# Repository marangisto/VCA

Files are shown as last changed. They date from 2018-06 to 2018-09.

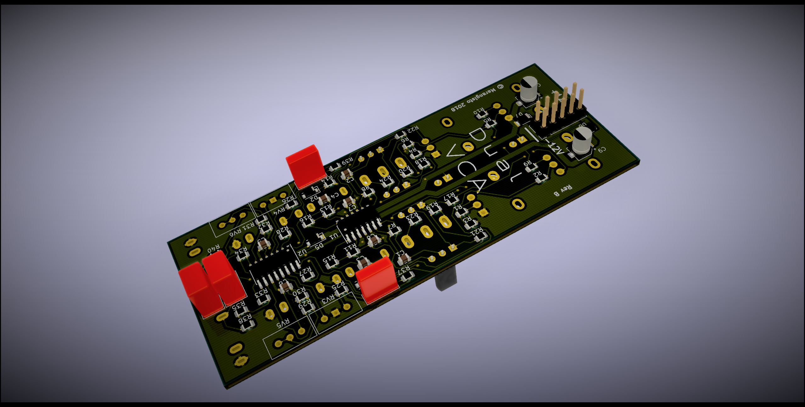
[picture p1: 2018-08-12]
board-RevB.png

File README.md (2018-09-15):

# VCA
DIY Modular VCA

Inspired by RJWSoft's Dual Log/Linear VCA but incorporating ideas from application notes
and use of the diode bias inputs in the OTA together with supply adjustements
to ensure both exponential and linear modes can drive levels all the way to zero.

To calibrate:

1) Set offset potentiometer so that its output viper is at 0V (measure on board).

2) Adjust the 100k trimmer (bottom-most) as close to 0mV as possible at output jack.
note that during this phase you may need to mix in adjustments of the 2k trimmer
to make this feasible.

3) Feed a 100Hz 10Vpp square signal into CV and adjust 2k trimmer (top-most) to minimize
feed-throgh on an oscilloscope.

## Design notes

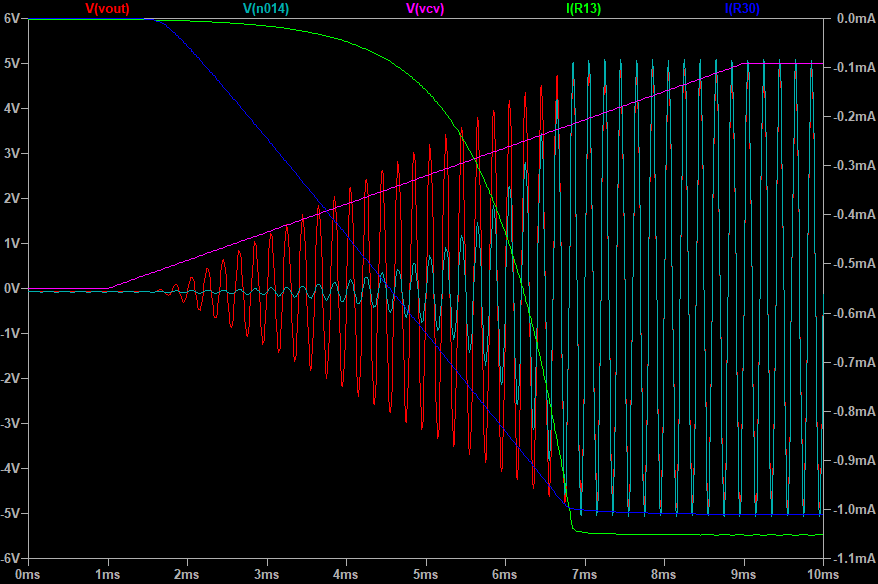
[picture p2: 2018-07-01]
response.png

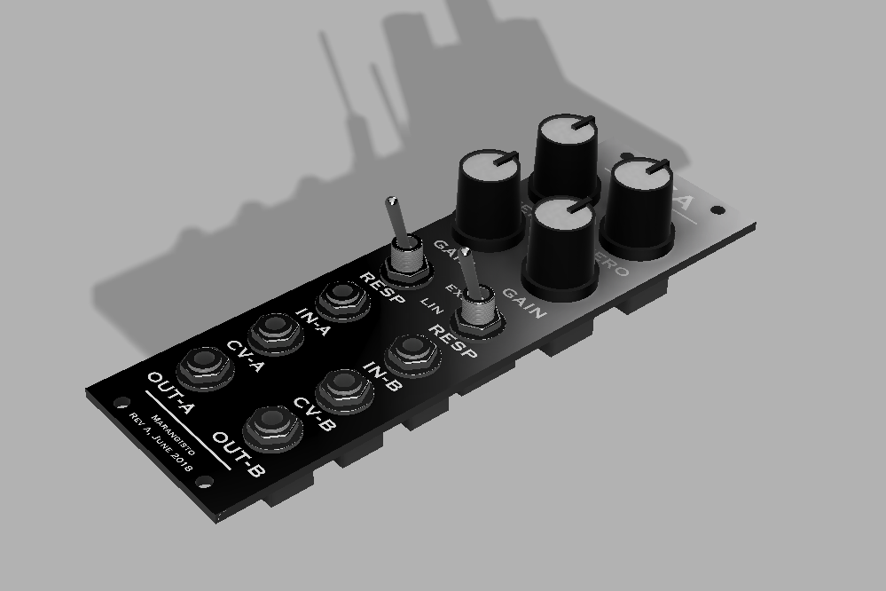
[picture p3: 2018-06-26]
vca-render.png

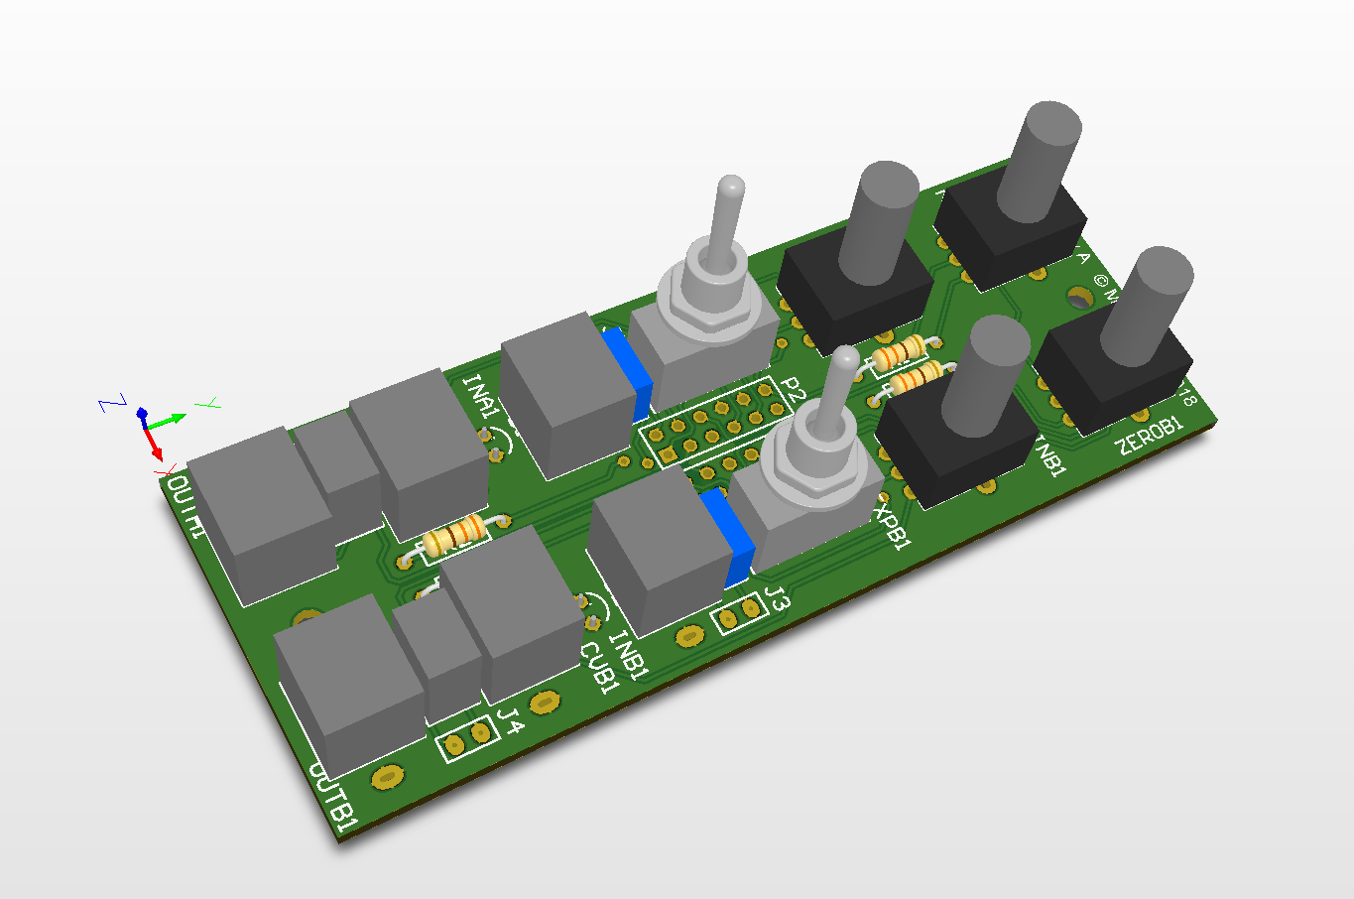
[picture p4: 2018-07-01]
ui.png

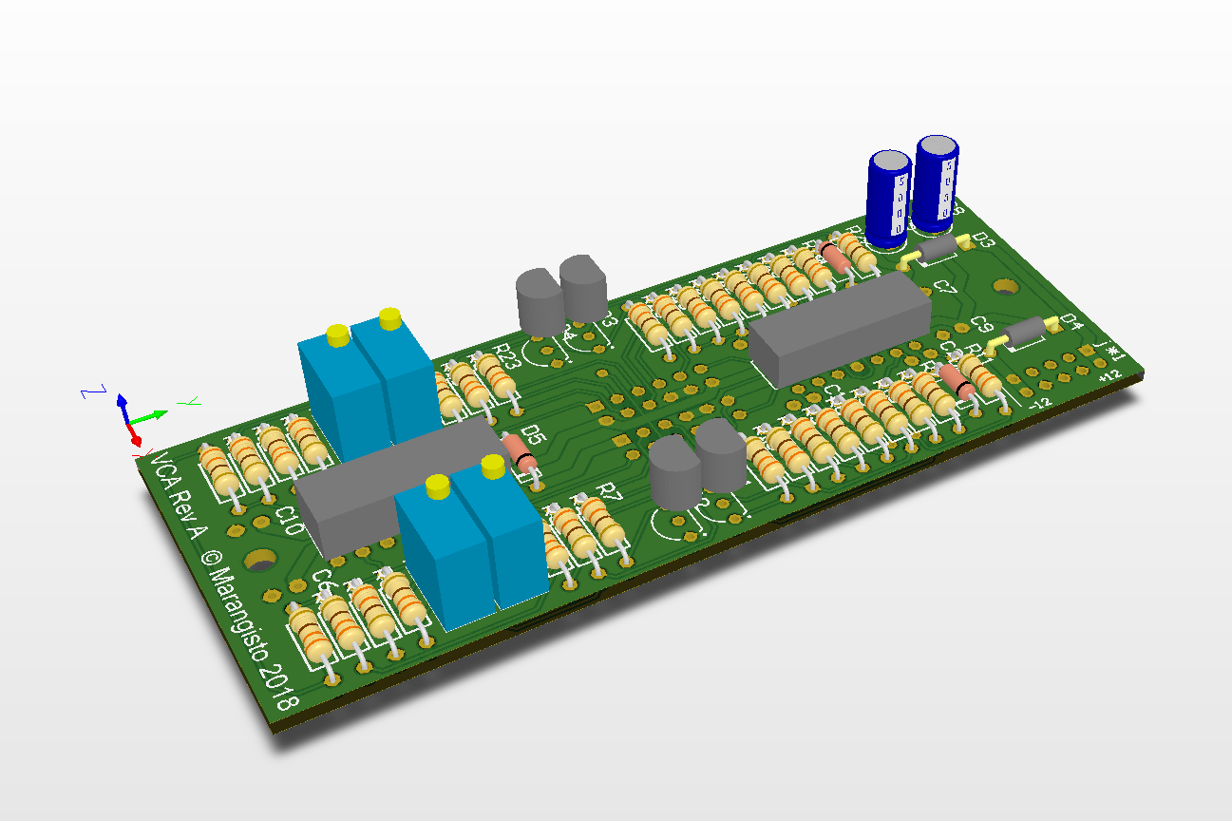
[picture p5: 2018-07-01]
board.png

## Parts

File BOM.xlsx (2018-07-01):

Comment | Description | Designator | Footprint | LibRef | Quantity | SGD | Total | 3X
2.2nF | CAPACITOR CERAMIC 0.1UF, 50V, X7R, 10%, RAD | C1, C2, C3, C4 | PCB-4018384-1 | CMP-3964680-3 | 4 | 0.363 | 1.452 | 12
Cap Pol2 | Electrolytic capacitor Radial lead 2.5 mm 10 µF 16 V 20 % (Ø) 4 mm Panasonic EEA-GA1C100H 1 pc(s) | C5, C8 | PCB-xswzn1jk2ejoevwvaoxh-1 | CMP-b868704b0d3c67af-1 | 2 | 0.264 | 0.528 | 6
100nF | CAPACITOR CERAMIC 0.1UF, 50V, X7R, 10%, RAD | C6, C7, C9, C10 | PCB-4018384-1 | CMP-3964680-3 | 4 | 0.042 | 0.168 | 12
1N4148 | DIODE GEN PURP 100V 200MA DO35 | D1, D2,D5 | PCB-rs5tsfd40ie4dftnk2d5-1 | CMP-814702-5 | 3 | 0.034 | 0.102 | 9
1N4007-T | 1.0 A Rectifier, 8 pF, 1000 V, -65 to 150 degC, 2-Pin DO-41 Plastic, RoHS, Tape and Reel | D3, D4 | DIOD-DO-41-P-2_V | CMP-815216-9 | 2 | 0.028 | 0.056 | 6
samtec TSW-105-07-G-D | Conn Unshrouded Header HDR 10 POS 2.54mm Solder ST Thru-Hole Automotive Bulk | j*1 | PCB-2.54 | CMP-fd383436ff4822ff-3 | 1 |  | 0.000 | 3
TE Connectivity / AMP 826942-6 | Wire-To-Board Connector, Straight, AMPMODU Mod II Series, Through Hole, Header, 12, 2.54 mm | P1, P2 | PCB-5yyv7wuue5ehtuetu923-1 | CMP-29e6e2989926f621-1 | 2 |  | 0.000 | 6
NPN | Transistor Npn Silicon 50v Ic=800ma To-18 Case Small Signal General Purpose Swit | Q1, Q3 | PCB-fs5arr6b0j1qpwda469g-1 | CMP-3cc2f4135df8e305-3 | 2 | 0.070 | 0.140 | 6
P2N2907AG | Transistor GP BJT PNP 60V 0.6A 3-Pin TO-92 Bulk | Q2, Q4 | PCB-fs5arr6b0j1qpwda469g-1 | CMP-3269fb6c5e11edae-1 | 2 | 0.070 | 0.140 | 6
130k | Generic Resistor | R1, R17 | PCB-scfsqlcj2xexsqh83e8b-1 | CMP-h62b46ec65u1fim3rs99-5 | 2 | 0.039 | 0.078 | 6
47k | Generic Resistor | R2, R18 | PCB-scfsqlcj2xexsqh83e8b-1 | CMP-h62b46ec65u1fim3rs99-5 | 2 | 0.039 | 0.078 | 6
100k | Generic Resistor | R3, R19 | PCB-scfsqlcj2xexsqh83e8b-1 | CMP-h62b46ec65u1fim3rs99-5 | 2 | 0.039 | 0.078 | 6
4k7 | Generic Resistor | R4, R9, R15, R20, R25, R31 | PCB-scfsqlcj2xexsqh83e8b-1 | CMP-h62b46ec65u1fim3rs99-5 | 6 | 0.039 | 0.234 | 18
33k | Generic Resistor | R5, R14, R21, R30 | PCB-scfsqlcj2xexsqh83e8b-1 | CMP-h62b46ec65u1fim3rs99-5 | 4 | 0.039 | 0.156 | 12
150k | Generic Resistor | R6, R13, R22, R29 | PCB-scfsqlcj2xexsqh83e8b-1 | CMP-h62b46ec65u1fim3rs99-5 | 4 | 0.039 | 0.156 | 12
9.1k | Generic Resistor | R7, R23 | PCB-scfsqlcj2xexsqh83e8b-1 | CMP-h62b46ec65u1fim3rs99-5 | 2 | 0.039 | 0.078 | 6
270k | Generic Resistor | R8, R24 | PCB-scfsqlcj2xexsqh83e8b-1 | CMP-h62b46ec65u1fim3rs99-5 | 2 | 0.039 | 0.078 | 6
680 | Generic Resistor | R10, R26 | PCB-scfsqlcj2xexsqh83e8b-1 | CMP-h62b46ec65u1fim3rs99-5 | 2 | 0.039 | 0.078 | 6
10k | Generic Resistor | R11, R27 | PCB-scfsqlcj2xexsqh83e8b-1 | CMP-h62b46ec65u1fim3rs99-5 | 2 | 0.039 | 0.078 | 6
1k | Generic Resistor | R12, R28 | PCB-scfsqlcj2xexsqh83e8b-1 | CMP-h62b46ec65u1fim3rs99-5 | 2 | 0.039 | 0.078 | 6
68k | Generic Resistor | R16, R32 | PCB-scfsqlcj2xexsqh83e8b-1 | CMP-h62b46ec65u1fim3rs99-5 | 2 | 0.039 | 0.078 | 6
100k | Res Cermet Trimmer 100K Ohm 10% 1/2W 21(Elec)/23(Mech)Turn 2.2mm (9.7 X 5 X 11.1mm) Pin Thru-Hole Tube | TRIM1, TRIM3 | PCB-grgx94mf10c7phwur416-1 | CMP-64faafae1c81bb3d-1 | 2 | 0.600 | 1.200 | 6
2k | Res Cermet Trimmer 100K Ohm 10% 1/2W 21(Elec)/23(Mech)Turn 2.2mm (9.7 X 5 X 11.1mm) Pin Thru-Hole Tube | TRIM2, TRIM4 | PCB-grgx94mf10c7phwur416-1 | CMP-64faafae1c81bb3d-1 | 2 | 0.600 | 1.200 | 6
TL074CN | Quad Low-Noise JFET-Input General-Purpose Operational Amplifier, 7 to 36 V, 0 to 70 degC, 14-pin DIP (N14), Pb-Free (RoHS) | U1 | TI-N14 | CMP-1321015-3 | 1 | 0.878 | 0.878 | 3
LM13700N | Dual Operational Transconductance Amplifier with Linearizing Diodes and Buffers, 16-pin MDIP | U2 | N16E | CMP-0055-00179-4 | 1 | 2.700 | 2.700 | 3
EPCOS B32529C224K | Cap Film 0.22uF 63V PET 10% (7.2 X 2.5 X 6.5mm) Radial Plastic Rectangular Can 5mm 125C Automotive Bulk | C1, C3 | B32529 | CMP-019cc8956d82de5b-1 | 2 | 0.248 | 0.496 | 6
1uF | Capacitor; Polyester Metallized; Cap 1 uF; Tol 5%; Vol-Rtg 63 VDC; Radial | C2, C4 | PCB-ka1zm55v8q6ppt5atpap-1 | CMP-7042b931eabbaf85-2 | 2 | 0.427 | 0.854 | 6
WQP-PJ398SM | 3.5mm Mono Jack PCB Mount | CVA1, CVB1, INA1, INB1, OUTA1, OUTB1 | PCB-msapmydrilbsl74io7e2-1 | CMP-4jg5qs8nbosmqasq0ji9-1 | 6 | 0.507 | 3.039 | 18
LED | Red 3 mm 50° Tinted Diffused 2 mcd 1.8 V Solid State LED Lamp Through Hole | D1, D2 | PCB-i0lu3ywj2mjd0tfwcgvk-1 | CMP-93ac5aa6a05f4c6b-6 | 2 | 0.075 | 0.150 | 6
Toggle Switch Latching 2 Pos NC C NO | Two positon latching toggle switch | EXPA1, EXPB1 | PCB-vhrr5z6azygjzs3qzahn-1 | CMP-a30bip09e2vzloklwtqo-1 | 2 | 0.258 | 0.516 | 6
100k | Vertical PCB Mount 9mm 100k Potentiometer | GAINA1, GAINB1, ZEROA1, ZEROB1 | Resistor foo | CMP-v7h8zal8rowsx2pq2wqv-3 | 4 | 0.922 | 3.688 | 12
TE Connectivity | AMPMODU Mod II Series, 2.54mm Pitch 2Way1 Row Straight PCB Header, Solder Term, 3A | J1, J2,J3,J4 | PCB-psmpzu51py3p54h2h388-1 | CMP-2811e342b2f0f7d6-5 | 4 |  | 0.000 | 12
TE Connectivity / AMP 826942-6 | Wire-To-Board Connector, Straight, AMPMODU Mod II Series, Through Hole, Header, 12, 2.54 mm | P1, P2 | PCB-5yyv7wuue5ehtuetu923-1 | CMP-29e6e2989926f621-1 | 2 |  | 0.000 | 6
47k | Generic Resistor | R1, R3 | PCB-scfsqlcj2xexsqh83e8b-1 | CMP-h62b46ec65u1fim3rs99-5 | 2 | 0.039 | 0.078 | 6
1k | Generic Resistor | R2, R4 | PCB-scfsqlcj2xexsqh83e8b-1 | CMP-h62b46ec65u1fim3rs99-5 | 2 | 0.039 | 0.078 | 6
Total |  |  |  |  | 88 |  | 18.712

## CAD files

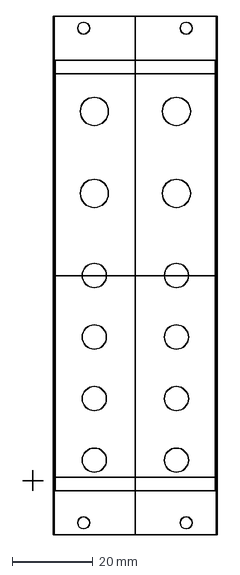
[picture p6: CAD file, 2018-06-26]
vca-panel.dxf
48.3 x 128.5 mm

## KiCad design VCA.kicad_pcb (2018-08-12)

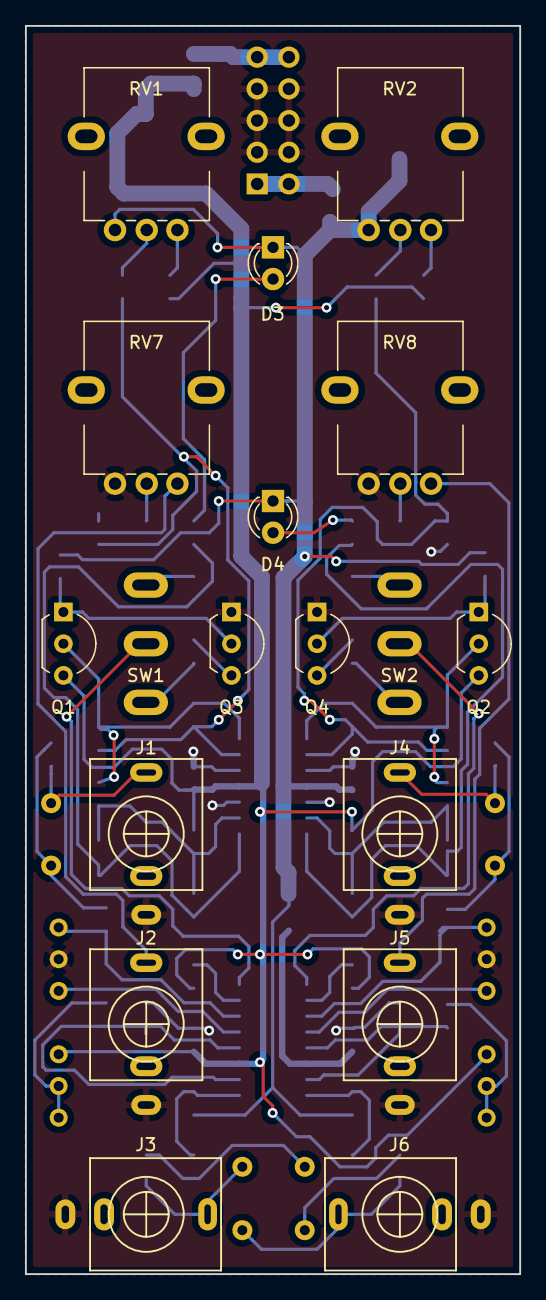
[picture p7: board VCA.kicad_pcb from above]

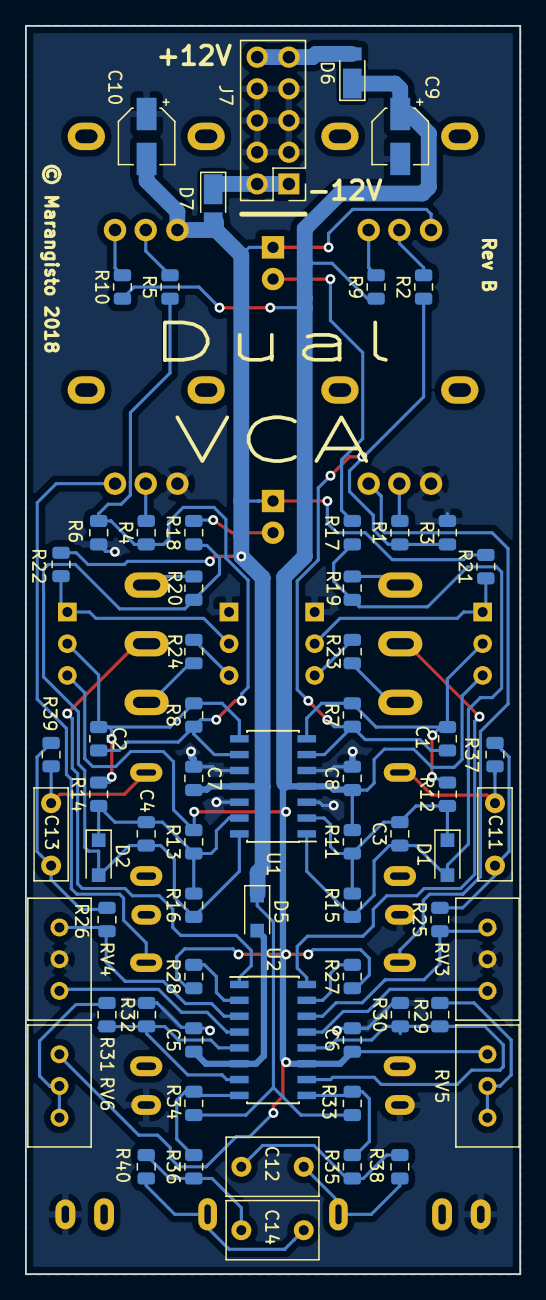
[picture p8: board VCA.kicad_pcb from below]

Board: 2 copper layers, 39.6 x 100.0 mm, 84 parts (66 on the bottom side), 54 nets.

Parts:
C1, C2: 2.2n; C_0805_2012Metric
C3, C4: 2,2n; C_0805_2012Metric
C5, C6, C7, C8: 100n; C_0805_2012Metric
C9, C10: 10u; CP_Elec_4x5.8
C11, C13: 220n; C_Rect_L7.2mm_W2.5mm_P5.00mm_FKS2_FKP2_MKS2_MKP2
C12, C14: 1u; C_Rect_L7.2mm_W4.5mm_P5.00mm_FKS2_FKP2_MKS2_MKP2
D1, D2, D5: 1N4148; D_SOD-123F
D3, D4: LED; LED_D3.0mm
D6, D7: DFLR1400-7; D_PowerDI-123
J1, J2, J3, J4, J5, J6: AudioJack2_Ground_Switch; PJ398SM
J7: Conn_02x05_Odd_Even; PinHeader_2x05_P2.54mm_Vertical
Q1, Q2: 2N2222; TO-92L_Inline_Wide
Q3, Q4: 2N2907; TO-92L_Inline_Wide
R1, R4: 100k; R_0805_2012Metric
R2, R5, R21, R22: 150k; R_0805_2012Metric
R3, R6, R7, R8, R33, R34: 4k7; R_0805_2012Metric
R9, R10, R15, R16: 47k; R_0805_2012Metric
R11, R13: 130k; R_0805_2012Metric
R12, R14: 680; R_0805_2012Metric
R17, R18, R35, R36: 1k; R_0805_2012Metric
R19, R20: 10k; R_0805_2012Metric
R23, R24: 9.1k; R_0805_2012Metric
R25, R26: 68k; R_0805_2012Metric
R27, R28, R30, R32: 33k; R_0805_2012Metric
R29, R31: 270k; R_0805_2012Metric
R37, R38, R39, R40: 0R; R_0805_2012Metric
RV1, RV2, RV7, RV8: 100k; AlpsRK09K
RV3, RV4: 2k; Potentiometer_Bourns_3296W_Vertical
RV5, RV6: 100k; Potentiometer_Bourns_3296W_Vertical
SW1, SW2: SW_SPDT; SP1MS1
U1: TL074; SOIC-14_3.9x8.7mm_P1.27mm
U2: LM13700; SOIC-16_3.9x9.9mm_P1.27mm

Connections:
+12V: C6.1, C8.1, C9.1, D6.1, Q1.3, Q2.3, R9.1, R10.1, R11.2, R13.2, R27.1, R28.1, RV5.1, RV6.1, U1.4, U2.11
-12V: C7.2, C10.2, D3.1, D4.1, D5.1, D7.2, R21.2, R22.2, R33.2, R34.2, RV1.3, RV2.3, U1.11
ABIA: SW1.2, U2.16
ABIB: SW2.2, U2.1
CVA: R1.2, RV7.2
CVB: R4.2, RV8.2
EXPA: R23.2, SW1.1
EXPB: R24.2, SW2.1
GND: C5.2, C6.2, C7.1, C8.2, C9.2, C10.1, J1.S, J2.S, J3.S, J4.S, J5.S, J6.S, J7.3, J7.4, J7.5, J7.6, J7.7, J7.8, Q3.1, Q4.1, R3.2, R6.2, R30.2, R32.2, RV3.2, RV4.2, RV7.3, RV8.3, U1.3, U1.5, U1.10, U1.12
INA: C11.1, R25.2, R37.1
INB: C13.1, R26.2, R39.1
LEDA: C3.1, D1.2, R15.1, R17.1, R19.2, U1.1
LEDB: C4.1, D2.2, R16.1, R18.1, R20.2, U1.14
LINA: R19.1, SW1.3
LINB: R20.1, SW2.3
unnamed: C1.1, Q1.2, R7.2, R12.2, U1.7
unnamed: C1.2, R1.1, R2.1, R3.1, R7.1, U1.6
unnamed: C2.1, Q2.2, R8.2, R14.2, U1.8
unnamed: C2.2, R4.1, R5.1, R6.1, R8.1, U1.9
unnamed: C3.2, D1.1, R11.1, R12.1, R15.2, U1.2
unnamed: C4.2, D2.1, R13.1, R14.1, R16.2, U1.13
unnamed: C5.1, D5.2, U2.6
unnamed: C11.2, J1.T, R37.2
unnamed: C12.2, J3.T, R38.2
unnamed: C13.2, J4.T, R39.2
unnamed: C14.2, J6.T, R40.2
unnamed: D3.2, R17.2
unnamed: D4.2, R18.2
unnamed: D6.2, J7.9, J7.10
unnamed: D7.1, J7.1, J7.2
unnamed: J2.T, RV7.1
unnamed: J5.T, RV8.1
unnamed: Q1.1, Q3.2, R21.1
unnamed: Q2.1, Q4.2, R22.1
unnamed: Q3.3, R23.1
unnamed: Q4.3, R24.1
unnamed: R9.2, RV1.1
unnamed: R10.2, RV2.1
unnamed: R25.1, RV3.1, U2.14
unnamed: R26.1, RV4.1, U2.3
unnamed: R27.2, U2.15
unnamed: R28.2, U2.2
unnamed: R29.1, RV5.2, RV5.3
unnamed: R29.2, R30.1, U2.10, U2.12
unnamed: R31.1, RV6.2, RV6.3
unnamed: R31.2, R32.1, U2.5, U2.7
unnamed: R33.1, R35.2, U2.9
unnamed: R34.1, R36.2, U2.8
unnamed: RV3.3, U2.13
unnamed: RV4.3, U2.4
OFFA: R2.2, RV1.2
OFFB: R5.2, RV2.2
OUTA: C12.1, R35.1, R38.1
OUTB: C14.1, R36.1, R40.1

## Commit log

2018-06-04 Connected CV driver stage with JFET.
2018-06-07 Renamed original prototype.
2018-06-07 Hacky CircuitMaker netlist parser to attempt Spicing.
2018-06-26 Added panel drawing and rendering.
    [vca-panel.dxf]
2018-06-28 Added stand-alone LM13700 circuit based TI datasheet but tweaked for offset control.
2018-06-28 First version of linear driver.
2018-06-29 Corrected input stage, zero offset circuit and supply bias for zero gain.
2018-06-30 Added LED indicator.
2018-06-30 Tidy up layout and use E24 resistors.
2018-07-01 Minor resistor adjustments.
2018-07-01 Added gerbers.
2018-07-01 Added bill-of-materials.
    [BOM.xlsx]
2018-07-01 Component counts for 3 sets.
    [BOM.xlsx]
2018-08-09 Original design sheet.
    [VCA.xlsx]
2018-08-10 Initial version of VCA revision B, manually 'ported' from CircuitMaker.
    [MainBoard.kicad_pcb, MainBoard.sch]
2018-08-11 Revision B of VCA control board.
    [ControlBoard.kicad_pcb, ControlBoard.sch]
2018-08-12 Added local footprint library.
2018-08-12 Added single-board SMD design.
    [SingleBoard.kicad_pcb, SingleBoard.sch]
2018-08-12 Removed redundant split board design.
    [ControlBoard.kicad_pcb, ControlBoard.sch, MainBoard.kicad_pcb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]
2018-08-12 Added rendering of revision B board.
2018-08-12 Moved single-board project to primary VCA design.
    [VCA.kicad_pcb, VCA.sch]
2018-08-12 Added BOM.
2018-08-12 Generated gerbers.
    [VCA-B.Cu.gbr, VCA-B.Mask.gbr, VCA-B.Paste.gbr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]
2018-08-12 Avoid traces outside pour.
    [VCA-B.Cu.gbr, VCA-B.Mask.gbr, VCA-B.Paste.gbr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]
2018-09-15 Updaded README with calibration instructions.

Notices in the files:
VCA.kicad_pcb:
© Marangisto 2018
